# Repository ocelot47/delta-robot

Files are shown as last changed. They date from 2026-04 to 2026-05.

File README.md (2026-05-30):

# Delta Robot Project (WIP)

A personal engineering project to design and build a 3-DOF Delta Robot, from
CAD and 3D-printed parts to embedded control, Python desktop control, motion
testing, and gripper experiments.

## Current Status

- Project stage: **Work in Progress**
- Mechanical/CAD design is available
- Prototype integration and ESP32 control are in progress
- Python GUI is available for serial control, testing, and visualization
- MG90S gripper servo control is included in the current firmware/app flow
- Final calibration and production-ready behavior are not finished yet

## What Is Included Right Now

- CAD assembly snapshots
- STL files for 3D printing (`filein3d_STL`)
- Assembly file (`assembly.sldasm`)
- ESP32 firmware (`napcode/code/code.ino`)
- Python desktop app (`napcode/code/main.py`)
- Camera candy detection module (`napcode/code/handlers/candy_detector.py`)
- Calibration measurement template (`napcode/code/calibration_measurements.md`)
- Reference images used for documentation

## Project Gallery

### Complete Assembly View
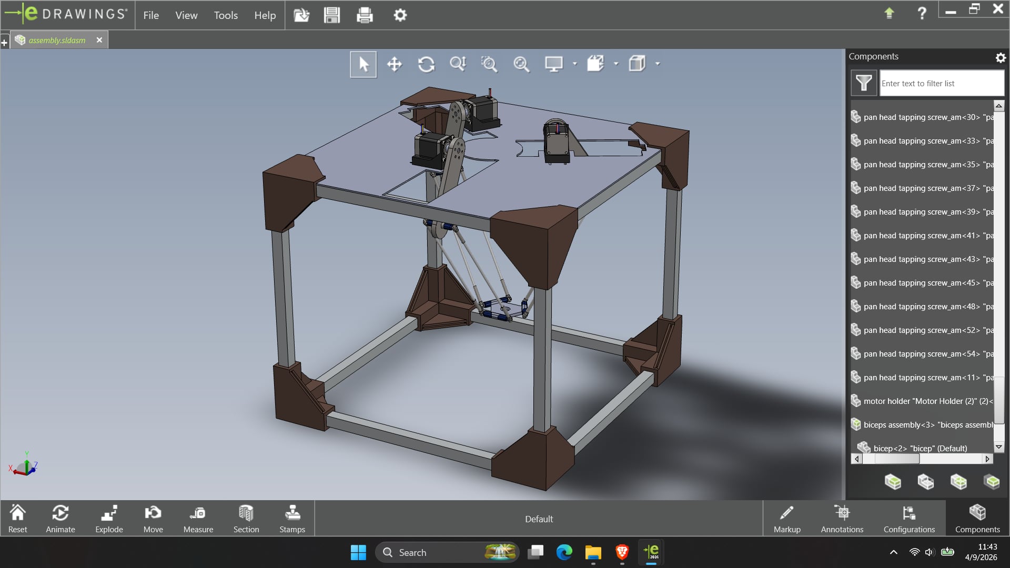
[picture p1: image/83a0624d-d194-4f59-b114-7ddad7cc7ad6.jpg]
Complete assembly CAD view

Overall CAD assembly of the Delta Robot frame, motor mounts, and arm linkage.

### Exploded Assembly View
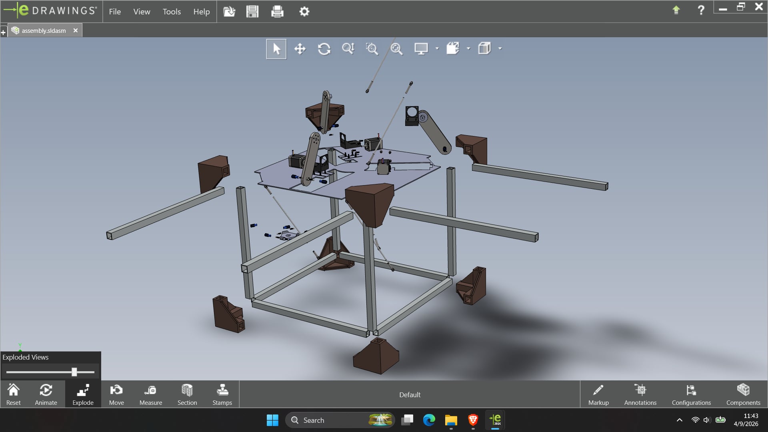
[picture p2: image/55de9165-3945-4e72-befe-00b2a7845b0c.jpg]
Exploded assembly CAD view

Exploded view showing how structural and moving components fit together.

### Top View Measurement
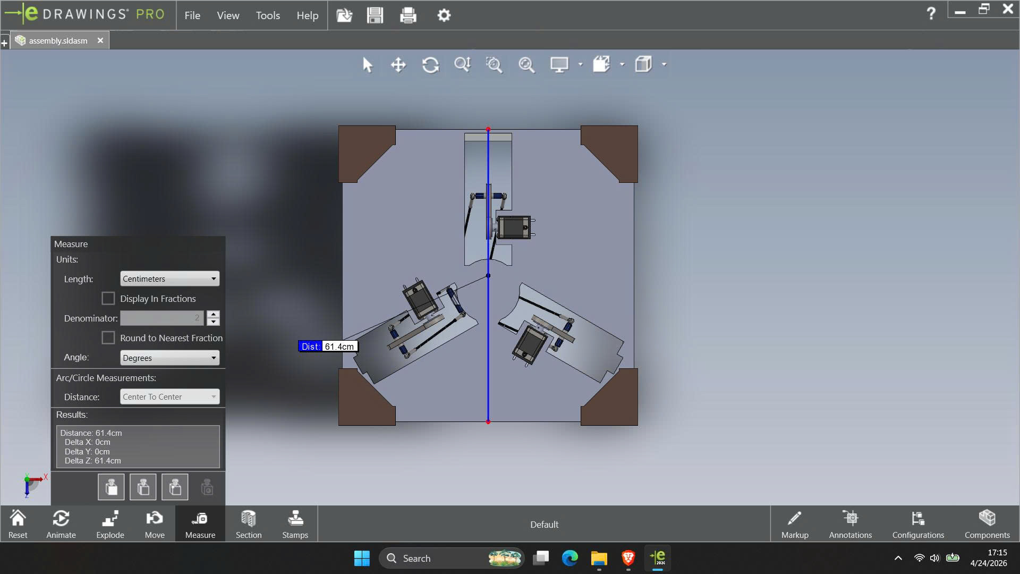
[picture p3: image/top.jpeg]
Top view CAD measurement

Top view with geometric spacing measurement used for frame and actuator placement checks.

### Side View Measurement
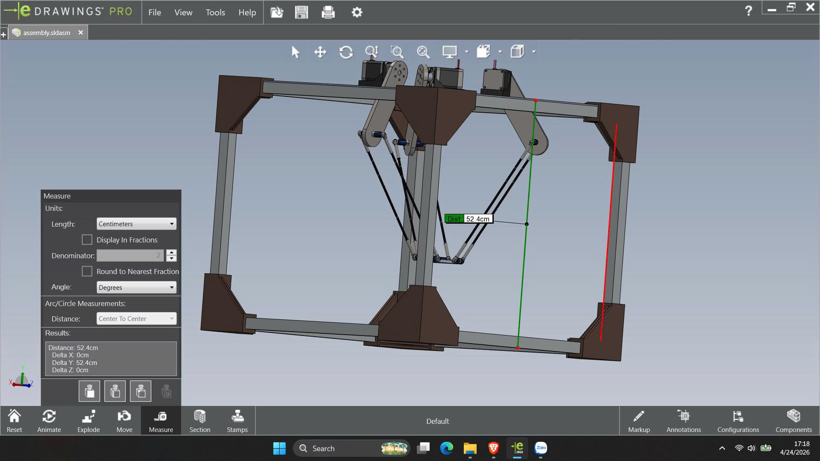
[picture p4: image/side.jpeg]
Side view CAD measurement

Side view with height/clearance measurement for workspace and vertical layout validation.

## Repository Highlights

- `image/`: screenshots, measurement views, and CAD references
- `image/filein3d_STL/`: printable STL component set
- `napcode/code/`: Python desktop app and ESP32 firmware
- `napcode/code/code.ino`: ESP32 JSON-over-Serial firmware
- `napcode/code/main.py`: desktop app entry point
- `napcode/code/handlers/candy_detector.py`: YOLO candy detection helper
- `napcode/code/calibration_measurements.md`: robot measurement worksheet

## Desktop App And Firmware

The desktop app is built with Python, CustomTkinter, PySerial, Matplotlib, and
NumPy, OpenCV, Pillow, and Ultralytics. It provides compact controls on the
left, a Matplotlib robot visualization on the right, menu items for plots,
camera support, candy detection, and a log console at the bottom.

The serial protocol is JSON-over-Serial for the current ESP32 firmware.

## Hardware Mapping

| Signal | GPIO |
|---|---:|
| STEP1 / Motor A | 32 |
| DIR1 / Motor A | 33 |
| STEP2 / Motor B | 18 |
| DIR2 / Motor B | 19 |
| STEP3 / Motor C | 25 |
| DIR3 / Motor C | 26 |
| LIMIT_A | 13 |
| LIMIT_B | 14 |
| LIMIT_C | 23 |
| ENABLE_PIN | 27 |
| MG90S gripper servo signal | 17 |

DRV8825 enable is active low: `LOW = enabled`, `HIGH = disabled`.

Limit switches are NC with `INPUT_PULLUP`: `false = normal`, `true = triggered
or wire fault`.

MG90S gripper:

- Servo signal default: `GPIO17`
- Servo power should use a stable external 5V supply; connect servo GND and
  ESP32 GND together.
- Default open angle: `180 deg`
- Default close angle: `50 deg`
- Default boot/start angle: `70 deg`
- Change these in the UI or in `code.ino` if your gripper geometry needs a
  smaller close limit.

## Install

```bash
pip install customtkinter pyserial matplotlib numpy opencv-python pillow ultralytics
```

Arduino libraries:

- `FastAccelStepper`
- `ArduinoJson` v6.x
- `Delta-Kinematics-Library`
- `ESP32Servo`

## Run

1. Upload `napcode/code/code.ino` to the ESP32.
2. Start the desktop app:

```bash
cd napcode/code
python main.py
```

3. Select the COM port, keep baudrate `115200`, then press `Connect`.

## Test Flow

1. Press `Enable motors`.
2. Check status and limit switches. All limits should be `false` when not pressed.
3. Use `Home A`, `Home B`, `Home C`, or `Home`.
4. Use `JOG / Single Motor` to move one motor.
5. Use `Multi Motor Control` to send `move_abc`.
6. Use `Rotate In Place Test` for the temporary motor-step pattern.
7. Use `Gripper Servo MG90S` to test open/close before running pick/place.
8. Use `Pick From A To B Simulation` for a step-position demo sequence. The
   sequence closes the gripper at Position A and opens it at Position B.
9. Use `Position` + `Move` only after IK config is correct for the real robot.

Candy detection:

- Put `best.pt` in the app folder, next to `main.py`.
- Start the app, scan/select camera, then press `Start Camera`.
- Tick `Detect candy` in the Camera panel.
- The preview draws bounding boxes and red center points. The panel shows the
  first candy center as image pixel coordinates `x/y`.
- Current detection is camera-only. It does not automatically move the robot
  until camera-to-robot calibration is added.

`Emergency Stop` stops app sequences and sends `{"cmd":"stop"}`. It does not
disable the drivers.

Home All behavior:

- Each motor moves toward its NC limit switch until triggered.
- Each motor retracts `HOMING_RETRACT_STEPS` from the just-triggered switch
  position. Default is `200` steps away from the switch.
- Firmware then reports `{"status":"homed","motor":"all"}`.
- The desktop app can optionally run a flexible `Post-Home Drop` move after
  `Home All`. Adjust A/B/C steps, speed, and accel in the app UI; no firmware
  upload is needed for later tuning.
- `Post-Home Drop` is disabled by default because firmware already retracts
  200 steps during homing.
- If the robot moves upward instead of downward, change the signs of A/B/C
  steps in the `Post-Home Drop` section.

## Supported Commands

```json
{"cmd":"enable"}
{"cmd":"disable"}
{"cmd":"stop"}
{"cmd":"status"}
{"cmd":"home"}
{"cmd":"home_motor","motor":"A"}
{"cmd":"move_motor","motor":"A","steps":1000,"speed":2000,"accel":1000}
{"cmd":"jog","motor":"A","dir":1,"steps":100}
{"cmd":"move_abc","a":1000,"b":0,"c":1000,"speed":2000,"accel":1000}
{"cmd":"set_ik_config","arm":100,"rod":250,"base":150,"platform":60,"stepsPerDeg":8.889,"offsetA":0,"offsetB":0,"offsetC":0,"signA":1,"signB":1,"signC":1}
{"cmd":"move_xyz","x":0,"y":0,"z":-200,"speed":2000,"accel":1000}
{"cmd":"gripper_open"}
{"cmd":"gripper_close"}
{"cmd":"gripper_close","angle":50}
{"cmd":"set_gripper","angle":90}
{"cmd":"set_gripper_limits","openAngle":180,"closedAngle":50}
```

Gripper status fields are included in normal status responses:

```json
{"gripperAttached":true,"gripperAngle":180,"gripperOpenAngle":180,"gripperClosedAngle":50}
```

The Program menu from the reference app is present as a placeholder only. The
original repo uses a different command protocol, so program upload was not
copied into this ESP32 JSON app.

## Next Milestones

- Finish mechanical assembly validation
- Refine control firmware and motion sequencing
- Add kinematics and trajectory testing
- Complete calibration measurements
- Tune repeatability and accuracy
- Publish final demo and full build guide

## Tools and Stack

- CAD / 3D design workflow
- 3D-printed mechanical parts (STL)
- Embedded control (Arduino/ESP-style `.ino` workflow)
- ESP32, DRV8825, limit switches, MG90S servo
- Python desktop GUI with serial communication and robot visualization
- OpenCV and Ultralytics YOLO for camera-based candy detection

## Note

This repository is actively updated while the robot is being developed.

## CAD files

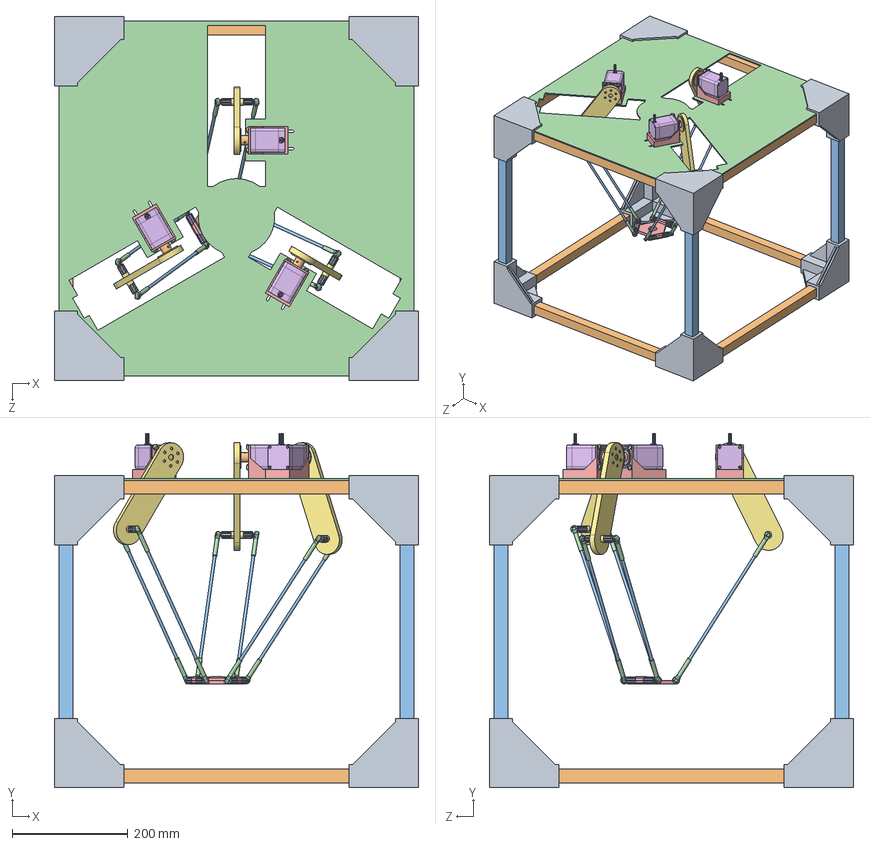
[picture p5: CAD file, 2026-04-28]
image/assembly.sldasm
630.0 x 613.2 x 630.0 mm
frame corner joint x 8
horizontal support frame x 8
vertical stand for frame x 4
motor mounting plate
Motor Holder (2) x 3
NEMA 17 x 3
bicep x 3
ball x 12
ball joint for biceps x 6
rotation transmittor x 3
forearm x 6
socket x 12
Effector platform 1
Ball joint x 6
pan head tapping screw_am x 24

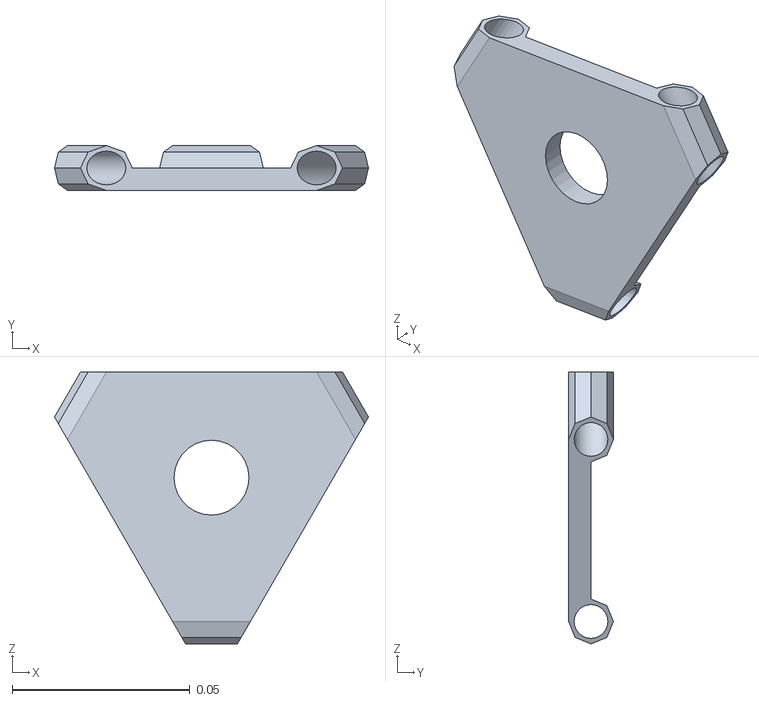
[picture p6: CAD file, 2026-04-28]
image/filein3d_STL/1xeffector_platform1.stl
0.0882 x 0.0126 x 0.0764

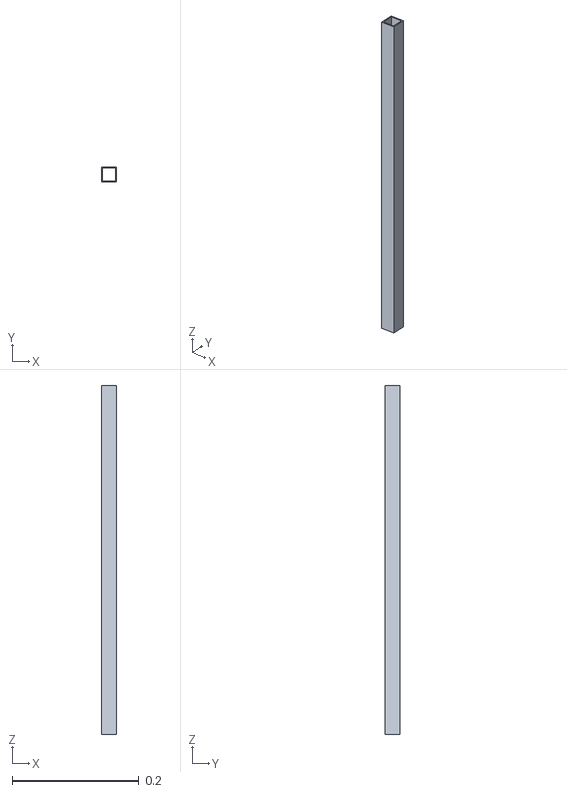
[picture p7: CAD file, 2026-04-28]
image/filein3d_STL/8xhorizontal_support_frame5.stl
0.024 x 0.024 x 0.55

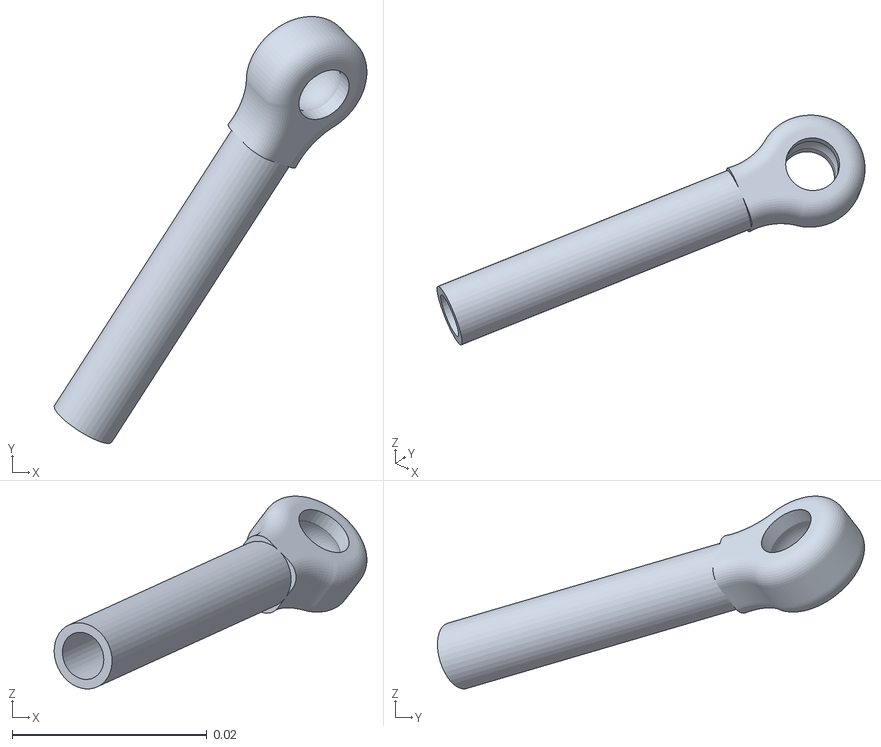
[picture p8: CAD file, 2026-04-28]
image/filein3d_STL/12xsocket_10.stl
0.0321 x 0.0439 x 0.0198

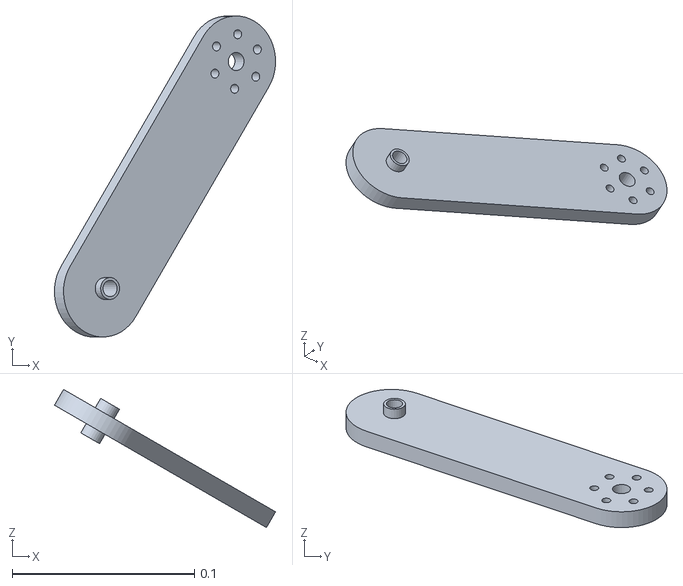
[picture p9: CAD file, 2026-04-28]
image/filein3d_STL/3xbicep_11.stl
0.121 x 0.176 x 0.0759

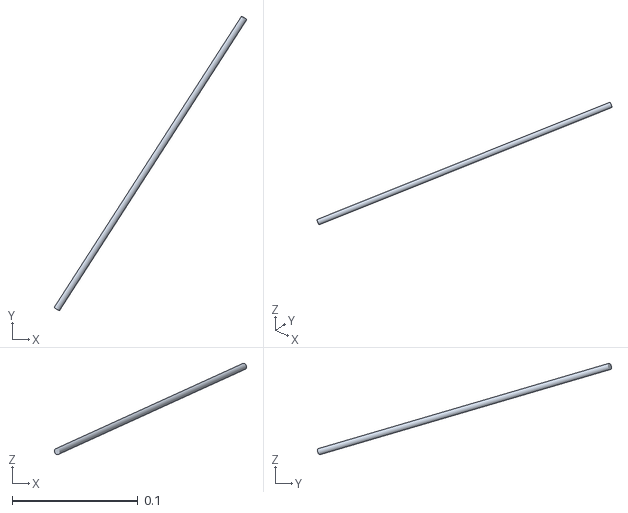
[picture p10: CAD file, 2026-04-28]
image/filein3d_STL/6xforearm_3.stl
0.153 x 0.234 x 0.0725

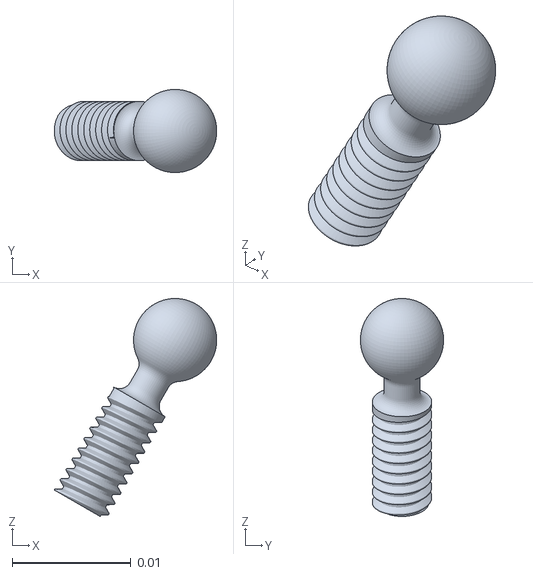
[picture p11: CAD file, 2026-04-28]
image/filein3d_STL/12xball_13.stl
0.0137 x 0.00699 x 0.0183

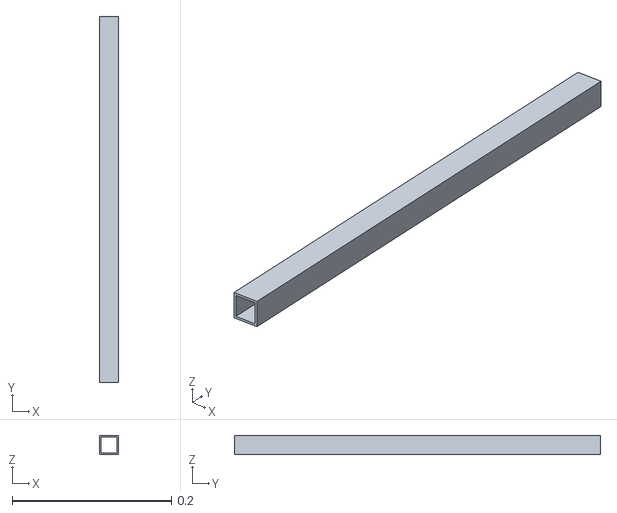
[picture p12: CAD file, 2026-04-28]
image/filein3d_STL/4xvertical_stand_for_frame_6.stl
0.024 x 0.46 x 0.024

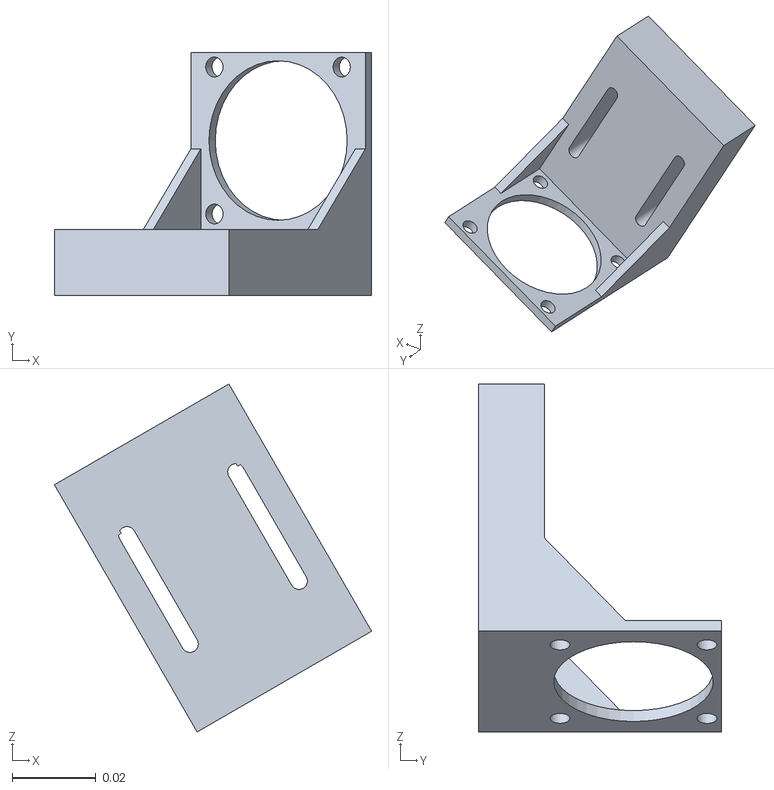
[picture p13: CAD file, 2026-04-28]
image/filein3d_STL/3xmotor_holder_12.stl
0.0756 x 0.058 x 0.0829

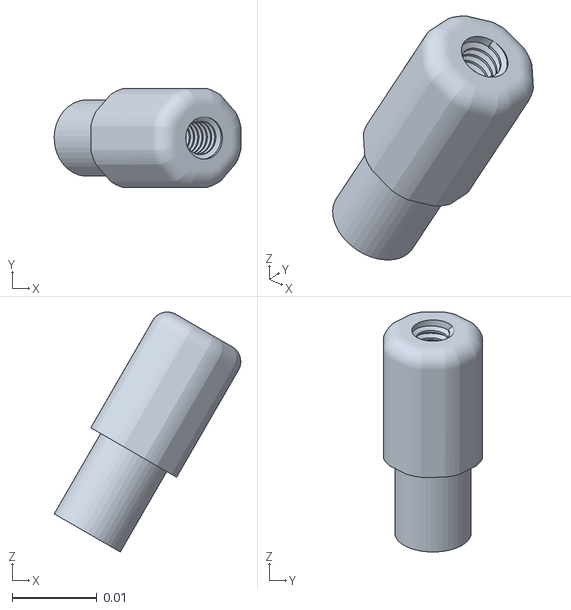
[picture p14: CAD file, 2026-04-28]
image/filein3d_STL/6xball_joint_for_biceps_14.stl
0.022 x 0.0117 x 0.0282

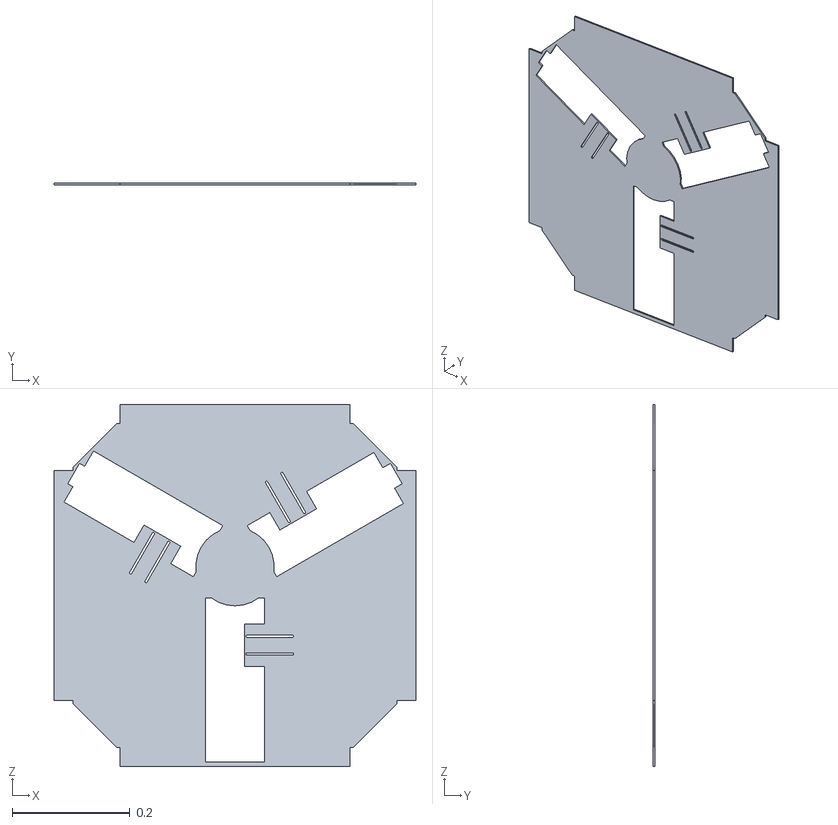
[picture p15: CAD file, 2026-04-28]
image/filein3d_STL/1xmotor_mounting_plate_7.stl
0.614 x 0.003 x 0.614

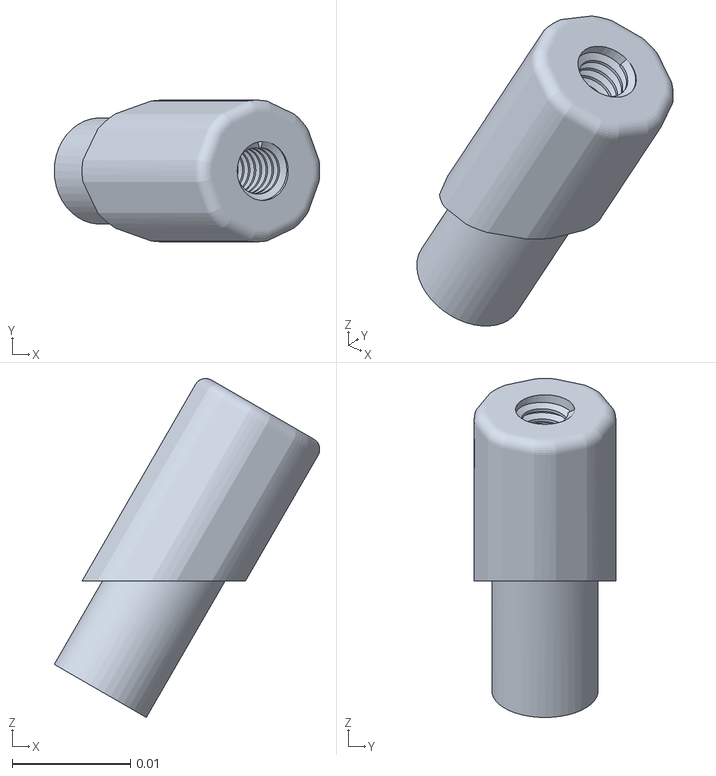
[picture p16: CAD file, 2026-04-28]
image/filein3d_STL/6xball_joint_2.stl
0.0225 x 0.012 x 0.0287

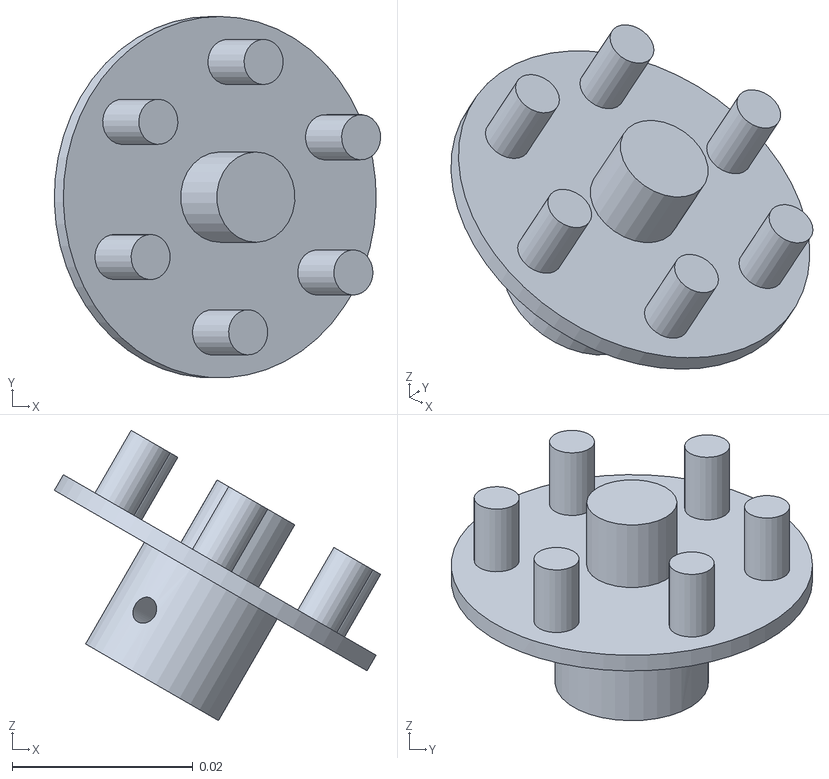
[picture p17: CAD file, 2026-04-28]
image/filein3d_STL/3xrotation_transmittor_9.stl
0.0361 x 0.04 x 0.0321

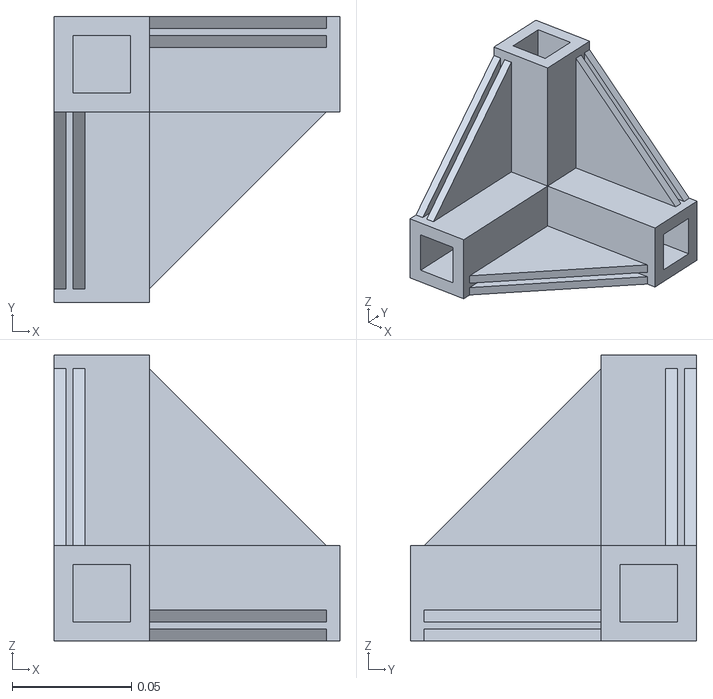
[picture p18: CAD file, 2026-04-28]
image/filein3d_STL/8xframe_corner_joint_4.stl
0.12 x 0.12 x 0.12

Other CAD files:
image/filein3d_STL/12xpan_head_tapping_screw_am-39PHT_4x13x11_6-slot-D-S.stl
image/filein3d_STL/12xpan_head_tapping_screw_am-28PHT_5x13x12_2-slot-D-S.stl

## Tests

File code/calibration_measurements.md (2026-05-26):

# Delta Robot Calibration Measurements

File nay dung de do va ghi thong so robot delta. Sau khi dien xong, gui lai
file nay de tinh:

- `stepsPerDeg`
- `offsetA/B/C`
- `signA/B/C`
- goc home thuc te
- gioi han goc tung motor
- thong so IK `arm/rod/base/platform`
- workspace X/Y/Z cua dau gap
- thong so hien thi 3D trong app

## 1. Thong Tin Chung

Ngay do:

Nguoi do:

Ghi chu robot:

```text

```

Microstep DRV8825 dang dung:

- [ ] Full step
- [ ] 1/2
- [ ] 1/4
- [ ] 1/8
- [ ] 1/16
- [ ] 1/32

Motor step angle:

- [ ] 1.8 deg/step
- [ ] 0.9 deg/step
- [ ] Khac:

Ti so truyen neu co:

```text
Motor truc tiep / pulley / gear:
Gear ratio:
Ghi chu:
```

## 2. Huong Dan Do Goc

Can chon mot moc do goc co dinh va dung nhat quan cho ca 3 motor.

Khuyen nghi:

- Dung mat phang ngang cua tam base lam moc `0 deg`.
- Do goc cua canh tay tren tu truc motor den khop noi voi 2 thanh song song.
- Ghi ro quy uoc:
  - goc duong la tay co len hay ha xuong
  - +step tren app lam tay di len hay di xuong

Moc do goc ban dang dung:

```text

```

Quy uoc goc duong:

```text

```

## 3. Hinh Hoc Robot Delta

Do bang mm. Neu kho do, chup anh va ghi mo ta.

### 3.1 Base Triangle

Tam giac co dinh phia tren, noi 3 truc motor.

| Thong so | Gia tri mm | Cach do / ghi chu |
|---|---:|---|
| Base side: khoang cach truc motor A-B |  |  |
| Base side: khoang cach truc motor B-C |  |  |
| Base side: khoang cach truc motor C-A |  |  |
| Base side trung binh se dung tinh IK |  |  |

Neu truc motor khong nam dung tren dinh tam giac, ghi offset:

```text

```

### 3.2 Platform Triangle

Tam giac nho o dau gap, noi 3 cap thanh song song.

| Thong so | Gia tri mm | Cach do / ghi chu |
|---|---:|---|
| Platform side: khop A-B |  |  |
| Platform side: khop B-C |  |  |
| Platform side: khop C-A |  |  |
| Platform side trung binh se dung tinh IK |  |  |

Offset tu tam platform den dau kep gap:

```text
X offset:
Y offset:
Z offset:
```

### 3.3 Upper Arm

Canh tay tren: tu truc motor den khop noi voi 2 thanh song song.

| Motor | Chieu dai upper arm mm | Ghi chu |
|---|---:|---|
| A |  |  |
| B |  |  |
| C |  |  |
| Trung binh dung tinh IK |  |  |

### 3.4 Forearm Rods

Moi canh co 2 thanh song song tu upper arm xuong platform.

| Canh | Rod 1 mm | Rod 2 mm | Trung binh | Ghi chu |
|---|---:|---:|---:|---|
| A |  |  |  |  |
| B |  |  |  |  |
| C |  |  |  |  |
| Trung binh dung tinh IK |  |  |  |  |

Khoang cach giua 2 rod song song cua moi canh:

| Canh | Khoang cach giua 2 rod mm | Ghi chu |
|---|---:|---|
| A |  |  |
| B |  |  |
| C |  |  |

## 4. Kiem Tra Limit Switch

Truoc khi do goc, kiem tra limit NC:

1. Chay app.
2. Connect ESP32.
3. Khi chua cham, limit phai la `false`.
4. Bam tay tung cong tac, limit tuong ung phai la `true`.

| Limit | Chua cham | Bam tay | Ghi chu |
|---|---|---|---|
| A | false / true | false / true |  |
| B | false / true | false / true |  |
| C | false / true | false / true |  |

## 5. Home All Va Goc Home

Sau khi bam `Home`:

- Motor nao cham limit truoc thi motor do lui `HOMING_RETRACT_STEPS`.
- Motor con lai tiep tuc home.
- Sau khi tat ca homed, app status `homed=true`.

Thu tu cham limit:

```text
1:
2:
3:
```

`HOMING_RETRACT_STEPS` dang dung trong firmware:

```text
200
```

Goc sau Home All:

| Motor | Step status sau Home All | Goc upper arm sau Home All | +step lam tay len/xuong | Ghi chu |
|---|---:|---:|---|---|
| A | 0 |  |  |  |
| B | 0 |  |  |  |
| C | 0 |  |  |  |

## 6. Tim Steps Per Degree

Lam tung motor rieng le. Khuyen nghi speed/accel thap.

Trong app:

```text
JOG / Single Motor
steps = 200
speed = 500
accel = 500
```

Sau moi lan chay, do lai goc upper arm.

### Motor A

| Lan do | Lenh | Step status tren app | Goc do duoc | Ghi chu |
|---|---:|---:|---:|---|
| Home | 0 | 0 |  |  |
| A +200 | +200 |  |  |  |
| A +400 | +400 |  |  |  |
| A -200 | -200 |  |  |  |

### Motor B

| Lan do | Lenh | Step status tren app | Goc do duoc | Ghi chu |
|---|---:|---:|---:|---|
| Home | 0 | 0 |  |  |
| B +200 | +200 |  |  |  |
| B +400 | +400 |  |  |  |
| B -200 | -200 |  |  |  |

### Motor C

| Lan do | Lenh | Step status tren app | Goc do duoc | Ghi chu |
|---|---:|---:|---:|---|
| Home | 0 | 0 |  |  |
| C +200 | +200 |  |  |  |
| C +400 | +400 |  |  |  |
| C -200 | -200 |  |  |  |

## 7. Gioi Han Goc Tung Canh

Muc tieu: tim goc cao nhat co the co len va goc thap nhat co the ha xuong
ma khong cham khung, khong cang rod, khong gay ket co khi.

Di chuyen rat cham:

```text
steps = 50 hoac 100
speed = 300 den 500
accel = 300 den 500
```

### Motor A

| Gioi han | Step status | Goc upper arm | Mo ta co khi |
|---|---:|---:|---|
| Cao nhat / co len toi da |  |  |  |
| Thap nhat / ha xuong toi da |  |  |  |

### Motor B

| Gioi han | Step status | Goc upper arm | Mo ta co khi |
|---|---:|---:|---|
| Cao nhat / co len toi da |  |  |  |
| Thap nhat / ha xuong toi da |  |  |  |

### Motor C

| Gioi han | Step status | Goc upper arm | Mo ta co khi |
|---|---:|---:|---|
| Cao nhat / co len toi da |  |  |  |
| Thap nhat / ha xuong toi da |  |  |  |

## 8. Workspace Dau Gap

Phan nay do gioi han thuc te cua diem dau gap/kep.

Chon truc toa do:

```text
X duong huong ve:
Y duong huong ve:
Z duong huong ve:
Goc toa do dat tai:
```

### 8.1 Tam Workspace

Vi tri dau gap sau Home All:

```text
X =
Y =
Z =
```

### 8.2 Gioi Han Len/Xuong

Tai tam XY, di chuyen Z len/xuong cham nhat co the.

| Gioi han | X | Y | Z | Step A | Step B | Step C | Ghi chu |
|---|---:|---:|---:|---:|---:|---:|---|
| Z cao nhat |  |  |  |  |  |  |  |
| Z thap nhat |  |  |  |  |  |  |  |

### 8.3 Gioi Han Trai/Phai/Truoc/Sau

O mot do cao Z an toan, tim gioi han X/Y.

Do cao Z khi test:

```text
Z =
```

| Huong | X | Y | Z | Step A | Step B | Step C | Ghi chu |
|---|---:|---:|---:|---:|---:|---:|---|
| Tien truoc toi da |  |  |  |  |  |  |  |
| Lui sau toi da |  |  |  |  |  |  |  |
| Trai toi da |  |  |  |  |  |  |  |
| Phai toi da |  |  |  |  |  |  |  |

### 8.4 Diem Test IK Neu Co

Neu app/firmware da move_xyz duoc, ghi diem command va diem thuc te.

| Diem | X lenh | Y lenh | Z lenh | X thuc | Y thuc | Z thuc | Ghi chu |
|---|---:|---:|---:|---:|---:|---:|---|
| P1 | 0 | 0 |  |  |  |  |  |
| P2 |  |  |  |  |  |  |  |
| P3 |  |  |  |  |  |  |  |
| P4 |  |  |  |  |  |  |  |

## 9. Gripper Servo MG90S

Goc start firmware hien tai:

```text
70 deg
```

| Trang thai | Goc command | Trang thai thuc te | Ghi chu |
|---|---:|---|---|
| Start | 70 |  |  |
| Open | 180 |  |  |
| Close | 50 |  |  |
| Close nho nhat an toan |  |  |  |

## 10. Loi / Bat Thuong Khi Do

```text

```

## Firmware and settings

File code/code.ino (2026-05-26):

// Delta Robot - ESP32 motor test + inverse kinematics firmware
//
// Protocol: JSON over Serial at 115200 baud.
// Limit switches are NC: normal = LOW, triggered/wire fault = HIGH.

#include <ArduinoJson.h>
#include <DeltaKinematics.h>
#include <FastAccelStepper.h>
#include <ESP32Servo.h>

// Stepper pins
#define STEP1  32
#define DIR1   33
#define STEP2  18
#define DIR2   19
#define STEP3  25
#define DIR3   26

// NC limit switches: normal = LOW, triggered or wire fault = HIGH.
#define LIMIT_A 13
#define LIMIT_B 14
#define LIMIT_C 23

// DRV8825 common enable: LOW = enabled, HIGH = disabled.
#define ENABLE_PIN 27

// MG90S gripper servo. Change this pin if GPIO17 is already used on your PCB.
#define GRIPPER_SERVO_PIN 17

const uint32_t DEFAULT_SPEED = 2000;
const uint32_t DEFAULT_ACCEL = 1000;

const int GRIPPER_SERVO_MIN_US = 500;
const int GRIPPER_SERVO_MAX_US = 2500;
const int GRIPPER_HARD_MIN_ANGLE = 0;
const int GRIPPER_HARD_MAX_ANGLE = 180;
const int GRIPPER_DEFAULT_START_ANGLE = 70;
const int GRIPPER_DEFAULT_OPEN_ANGLE = 180;
const int GRIPPER_DEFAULT_CLOSED_ANGLE = 50;

// Homing moves "bung ra" in HOME_OUT_SIGN direction until the switch triggers,
// then retracts ("thu lai") in the opposite direction until the switch releases.
const uint32_t HOMING_SPEED = 800;
const uint32_t HOMING_ACCEL = 800;
const int32_t HOME_OUT_SIGN_A = 1;
const int32_t HOME_OUT_SIGN_B = 1;
const int32_t HOME_OUT_SIGN_C = 1;
const int32_t HOMING_SEARCH_CHUNK_STEPS = 300;
const int32_t HOMING_RETRACT_STEPS = 200;
const int32_t HOMING_MAX_RETRACT_STEPS = 6000;
// IK defaults. Tune these for the real robot.
float ikArm = 100.0f;
float ikRod = 250.0f;
float ikBase = 150.0f;
float ikPlatform = 60.0f;
float stepsPerDeg = 8.889f;
int32_t ikOffsetA = 0;
int32_t ikOffsetB = 0;
int32_t ikOffsetC = 0;
int32_t ikSignA = 1;
int32_t ikSignB = 1;
int32_t ikSignC = 1;

FastAccelStepperEngine engine = FastAccelStepperEngine();
FastAccelStepper *motorA = nullptr;
FastAccelStepper *motorB = nullptr;
FastAccelStepper *motorC = nullptr;
Servo gripperServo;

DeltaKinematics DK(100.0f, 250.0f, 150.0f, 60.0f);
StaticJsonDocument<384> doc;

bool driversEnabled = false;
bool homedA = false;
bool homedB = false;
bool homedC = false;
bool movementPending = false;
bool homingActive = false;
bool homingAll = false;
uint8_t homingSearchMask = 0;
uint8_t homingRetractMask = 0;
int32_t homingRetractedA = 0;
int32_t homingRetractedB = 0;
int32_t homingRetractedC = 0;
bool homingRetractStartedA = false;
bool homingRetractStartedB = false;
bool homingRetractStartedC = false;
int32_t activeDirA = 0;
int32_t activeDirB = 0;
int32_t activeDirC = 0;

bool pendingIkMove = false;
bool xyzValid = false;
float lastX = 0.0f;
float lastY = 0.0f;
float lastZ = 0.0f;
float lastThetaA = 0.0f;
float lastThetaB = 0.0f;
float lastThetaC = 0.0f;
float pendingX = 0.0f;
float pendingY = 0.0f;
float pendingZ = 0.0f;
float pendingThetaA = 0.0f;
float pendingThetaB = 0.0f;
float pendingThetaC = 0.0f;

bool gripperAttached = false;
int gripperServoChannel = -1;
int gripperAngle = GRIPPER_DEFAULT_START_ANGLE;
int gripperOpenAngle = GRIPPER_DEFAULT_OPEN_ANGLE;
int gripperClosedAngle = GRIPPER_DEFAULT_CLOSED_ANGLE;

enum MotorBit {
  MOTOR_A_BIT = 1,
  MOTOR_B_BIT = 2,
  MOTOR_C_BIT = 4,
};

bool limitA() { return digitalRead(LIMIT_A) == HIGH; }
bool limitB() { return digitalRead(LIMIT_B) == HIGH; }
bool limitC() { return digitalRead(LIMIT_C) == HIGH; }

int32_t signOf(int32_t value) {
  // Trả về dấu của số step để biết motor đang đi theo chiều nào.
  if (value > 0) return 1;
  if (value < 0) return -1;
  return 0;
}

int32_t abs32(int32_t value) {
  // Lấy trị tuyệt đối cho số int32_t.
  return value < 0 ? -value : value;
}

int32_t homeOutSign(uint8_t bit) {
  // Trả về chiều đi ra ngoài để tìm công tắc hành trình của từng motor.
  if (bit == MOTOR_A_BIT) return HOME_OUT_SIGN_A;
  if (bit == MOTOR_B_BIT) return HOME_OUT_SIGN_B;
  if (bit == MOTOR_C_BIT) return HOME_OUT_SIGN_C;
  return -1;
}

int32_t pos(FastAccelStepper *stepper) {
  // Đọc vị trí step hiện tại của motor, nếu motor chưa init thì trả 0.
  return stepper ? stepper->getCurrentPosition() : 0;
}

bool isBusy() {
  // Kiểm tra có motor nào đang chạy không.
  return (motorA && motorA->isRunning()) ||
         (motorB && motorB->isRunning()) ||
         (motorC && motorC->isRunning());
}

void sendJson(JsonDocument &out) {
  // Gửi một object JSON ra Serial, kết thúc bằng newline.
  serializeJson(out, Serial);
  Serial.println();
}

void addCommonStatus(JsonDocument &out) {
  // Gắn các field status chung vào mọi response gửi về app.
  out["a"] = pos(motorA);
  out["b"] = pos(motorB);
  out["c"] = pos(motorC);
  out["limitA"] = limitA();
  out["limitB"] = limitB();
  out["limitC"] = limitC();
  out["enabled"] = driversEnabled;
  out["homed"] = homedA && homedB && homedC;
  out["moving"] = isBusy() || homingActive;
  out["gripperAttached"] = gripperAttached;
  out["gripperAngle"] = gripperAngle;
  out["gripperOpenAngle"] = gripperOpenAngle;
  out["gripperClosedAngle"] = gripperClosedAngle;
  out["xyzValid"] = xyzValid;
  if (xyzValid) {
    out["x"] = lastX;
    out["y"] = lastY;
    out["z"] = lastZ;
    out["thetaA"] = lastThetaA;
    out["thetaB"] = lastThetaB;
    out["thetaC"] = lastThetaC;
  }
}

void sendStatus(const char *status = nullptr, const char *motor = nullptr) {
  // Gửi status chuẩn về app, có thể kèm tên motor đang xử lý.
  StaticJsonDocument<512> out;
  out["status"] = status ? status : ((isBusy() || homingActive) ? "moving" : "idle");
  if (motor) out["motor"] = motor;
  addCommonStatus(out);
  sendJson(out);
}

void sendError(const char *msg) {
  // Gửi lỗi về app nhưng vẫn kèm status hiện tại để UI cập nhật được.
  StaticJsonDocument<512> out;
  out["status"] = "error";
  out["msg"] = msg;
  addCommonStatus(out);
  sendJson(out);
}

void setDrivers(bool enabled) {
  // Điều khiển ENABLE chung của 3 DRV8825: LOW bật, HIGH tắt.
  driversEnabled = enabled;
  digitalWrite(ENABLE_PIN, enabled ? LOW : HIGH);
}

int constrainGripperAngle(int angle) {
  // Giới hạn góc servo kẹp trong khoảng open/close đã cấu hình.
  int lo = min(gripperOpenAngle, gripperClosedAngle);
  int hi = max(gripperOpenAngle, gripperClosedAngle);
  return constrain(angle, lo, hi);
}

void writeGripperAngle(int angle) {
  // Ghi góc servo kẹp và lưu lại gripperAngle để trả status.
  gripperAngle = constrainGripperAngle(angle);
  if (gripperAttached) {
    gripperServo.write(gripperAngle);
  }
}

void setGripperLimits(int openAngle, int closedAngle) {
  // Cập nhật giới hạn mở/kẹp của servo từ app.
  gripperOpenAngle = constrain(openAngle, GRIPPER_HARD_MIN_ANGLE, GRIPPER_HARD_MAX_ANGLE);
  gripperClosedAngle = constrain(closedAngle, GRIPPER_HARD_MIN_ANGLE, GRIPPER_HARD_MAX_ANGLE);
  writeGripperAngle(gripperAngle);
}

void applyConfig(uint32_t speed, uint32_t accel) {
  // Áp tốc độ/gia tốc cho cả 3 stepper.
  speed = max((uint32_t)1, speed);
  accel = max((uint32_t)1, accel);
  if (motorA) { motorA->setSpeedInHz(speed); motorA->setAcceleration(accel); }
  if (motorB) { motorB->setSpeedInHz(speed); motorB->setAcceleration(accel); }
  if (motorC) { motorC->setSpeedInHz(speed); motorC->setAcceleration(accel); }
}

void clearActiveDirs() {
  // Xóa chiều chạy hiện tại, dùng sau khi dừng hoặc move xong.
  activeDirA = 0;
  activeDirB = 0;
  activeDirC = 0;
}

void cancelPendingIk() {
  // Hủy move_xyz đang chờ commit nếu move bị stop/lỗi.
  pendingIkMove = false;
}

void stopAllMotors() {
  // Dừng khẩn cấp toàn bộ motor và reset các state homing/move.
  if (motorA) motorA->forceStop();
  if (motorB) motorB->forceStop();
  if (motorC) motorC->forceStop();
  movementPending = false;
  homingActive = false;
  homingSearchMask = 0;
  homingRetractMask = 0;
  homingAll = false;
  homingRetractStartedA = false;
  homingRetractStartedB = false;
  homingRetractStartedC = false;
  clearActiveDirs();
  cancelPendingIk();
}

uint8_t bitForMotor(const char *motor) {
  // Chuyển tên motor A/B/C hoặc 1/2/3 thành bit mask nội bộ.
  if (!motor) return 0;
  if (strcmp(motor, "A") == 0 || strcmp(motor, "1") == 0) return MOTOR_A_BIT;
  if (strcmp(motor, "B") == 0 || strcmp(motor, "2") == 0) return MOTOR_B_BIT;
  if (strcmp(motor, "C") == 0 || strcmp(motor, "3") == 0) return MOTOR_C_BIT;
  return 0;
}

const char *nameForBit(uint8_t bit) {
  // Chuyển bit mask motor thành tên A/B/C để trả status.
  if (bit == MOTOR_A_BIT) return "A";
  if (bit == MOTOR_B_BIT) return "B";
  if (bit == MOTOR_C_BIT) return "C";
  return "?";
}

bool limitForBit(uint8_t bit) {
  // Đọc limit switch tương ứng với motor bit.
  if (bit == MOTOR_A_BIT) return limitA();
  if (bit == MOTOR_B_BIT) return limitB();
  if (bit == MOTOR_C_BIT) return limitC();
  return true;
}

FastAccelStepper *stepperForBit(uint8_t bit) {
  // Lấy pointer stepper tương ứng với motor bit.
  if (bit == MOTOR_A_BIT) return motorA;
  if (bit == MOTOR_B_BIT) return motorB;
  if (bit == MOTOR_C_BIT) return motorC;
  return nullptr;
}

void markHomed(uint8_t bit) {
  // Đánh dấu motor đã homed.
  if (bit == MOTOR_A_BIT) homedA = true;
  if (bit == MOTOR_B_BIT) homedB = true;
  if (bit == MOTOR_C_BIT) homedC = true;
}

void clearHomed(uint8_t bit) {
  // Xóa trạng thái homed của motor khi bắt đầu homing lại hoặc lỗi.
  if (bit == MOTOR_A_BIT) homedA = false;
  if (bit == MOTOR_B_BIT) homedB = false;
  if (bit == MOTOR_C_BIT) homedC = false;
}

int32_t &homingRetractedForBit(uint8_t bit) {
  // Tham chiếu tới biến đếm step đã lùi sau khi chạm limit.
  if (bit == MOTOR_A_BIT) return homingRetractedA;
  if (bit == MOTOR_B_BIT) return homingRetractedB;
  return homingRetractedC;
}

bool &homingRetractStartedForBit(uint8_t bit) {
  // Tham chiếu tới cờ motor đã bắt đầu lùi khỏi limit hay chưa.
  if (bit == MOTOR_A_BIT) return homingRetractStartedA;
  if (bit == MOTOR_B_BIT) return homingRetractStartedB;
  return homingRetractStartedC;
}

void moveHomingSearchChunk(uint8_t bit) {
  // Cho một motor đi từng đoạn nhỏ theo chiều tìm limit.
  FastAccelStepper *stepper = stepperForBit(bit);
  if (stepper && !stepper->isRunning()) {
    stepper->move(homeOutSign(bit) * HOMING_SEARCH_CHUNK_STEPS);
  }
}

void moveHomingRetractChunk(uint8_t bit) {
  // Cho motor đã chạm limit lùi đúng HOMING_RETRACT_STEPS rồi dừng.
  FastAccelStepper *stepper = stepperForBit(bit);
  if (!stepper || stepper->isRunning()) return;
  int32_t steps = -homeOutSign(bit) * HOMING_RETRACT_STEPS;
  stepper->move(steps);
  homingRetractedForBit(bit) += abs32(steps);
  homingRetractStartedForBit(bit) = true;
}

bool limitBlocksDelta(uint8_t bit, int32_t delta) {
  // Chặn move nếu limit đang triggered và lệnh còn đi tiếp vào limit.
  if (!limitForBit(bit)) return false;
  int32_t dir = signOf(delta);
  if (dir == 0) return true;
  return dir == homeOutSign(bit);
}

bool movingIntoLimit() {
  // Kiểm tra motor đang chạy có đâm vào limit hay không.
  return (limitA() && activeDirA == HOME_OUT_SIGN_A) ||
         (limitB() && activeDirB == HOME_OUT_SIGN_B) ||
         (limitC() && activeDirC == HOME_OUT_SIGN_C);
}

bool canStartMotion(int32_t a, int32_t b, int32_t c) {
  // Kiểm tra điều kiện trước khi bắt đầu move_abc/move_motor.
  if (!driversEnabled) {
    sendError("motors_disabled");
    return false;
  }
  if (homingActive || isBusy()) {
    sendError("busy");
    return false;
  }
  if (limitBlocksDelta(MOTOR_A_BIT, a) ||
      limitBlocksDelta(MOTOR_B_BIT, b) ||
      limitBlocksDelta(MOTOR_C_BIT, c)) {
    sendError("limit_triggered_reverse_allowed_only");
    return false;
  }
  return true;
}

bool startMoveABC(int32_t a, int32_t b, int32_t c, uint32_t speed,
                  uint32_t accel, bool fromIk = false) {
  // Bắt đầu chạy tương đối 3 motor theo số step A/B/C.
  if (!canStartMotion(a, b, c)) return false;
  applyConfig(speed, accel);

  activeDirA = signOf(a);
  activeDirB = signOf(b);
  activeDirC = signOf(c);

  if (a != 0 && motorA) motorA->move(a);
  if (b != 0 && motorB) motorB->move(b);
  if (c != 0 && motorC) motorC->move(c);

  if (a == 0 && b == 0 && c == 0) {
    clearActiveDirs();
    sendStatus("done");
    return true;
  }

  movementPending = true;
  pendingIkMove = fromIk;
  if (!fromIk) {
    xyzValid = false;
  }
  sendStatus("moving");
  return true;
}

void commitPendingIk() {
  // Khi move_xyz hoàn tất, commit x/y/z/theta cuối cùng vào status.
  if (!pendingIkMove) return;
  lastX = pendingX;
  lastY = pendingY;
  lastZ = pendingZ;
  lastThetaA = pendingThetaA;
  lastThetaB = pendingThetaB;
  lastThetaC = pendingThetaC;
  xyzValid = true;
  pendingIkMove = false;
}

int32_t thetaToSteps(float theta, int32_t signValue, int32_t offset) {
  // Đổi góc IK sang target step theo sign/offset từng motor.
  return offset + (int32_t)(theta * stepsPerDeg * (float)signValue);
}

void startMoveXYZ(float x, float y, float z, uint32_t speed, uint32_t accel) {
  // Tính IK cho XYZ rồi chuyển thành move_abc tương đối.
  if (DK.inverse(x, y, z) != 1) {
    sendError("ik_fail");
    return;
  }

  int32_t targetA = thetaToSteps(DK.a, ikSignA, ikOffsetA);
  int32_t targetB = thetaToSteps(DK.b, ikSignB, ikOffsetB);
  int32_t targetC = thetaToSteps(DK.c, ikSignC, ikOffsetC);
  int32_t deltaA = targetA - pos(motorA);
  int32_t deltaB = targetB - pos(motorB);
  int32_t deltaC = targetC - pos(motorC);

  pendingX = x;
  pendingY = y;
  pendingZ = z;
  pendingThetaA = DK.a;
  pendingThetaB = DK.b;
  pendingThetaC = DK.c;

  if (deltaA == 0 && deltaB == 0 && deltaC == 0) {
    pendingIkMove = true;
    commitPendingIk();
    sendStatus("done");
    return;
  }

  if (!startMoveABC(deltaA, deltaB, deltaC, speed, accel, true)) {
    cancelPendingIk();
  }
}

void startHomeMask(uint8_t mask, bool all) {
  // Khởi động homing cho một motor hoặc cả 3 motor.
  if (!driversEnabled) {
    sendError("motors_disabled");
    return;
  }
  if (homingActive || isBusy()) {
    sendError("busy");
    return;
  }

  homingSearchMask = mask;
  homingRetractMask = 0;
  homingAll = all;
  homingActive = homingSearchMask != 0;
  homingRetractedA = 0;
  homingRetractedB = 0;
  homingRetractedC = 0;
  homingRetractStartedA = false;
  homingRetractStartedB = false;
  homingRetractStartedC = false;
  applyConfig(HOMING_SPEED, HOMING_ACCEL);

  if (homingSearchMask & MOTOR_A_BIT) clearHomed(MOTOR_A_BIT);
  if (homingSearchMask & MOTOR_B_BIT) clearHomed(MOTOR_B_BIT);
  if (homingSearchMask & MOTOR_C_BIT) clearHomed(MOTOR_C_BIT);
  xyzValid = false;
  cancelPendingIk();

  sendStatus("homing", all ? "all" : nameForBit(mask));
}

void processHoming() {
  // State machine homing: motor nào chạm trước thì lùi, motor khác tiếp tục tìm limit.
  if (!homingActive) return;

  uint8_t bits[] = {MOTOR_A_BIT, MOTOR_B_BIT, MOTOR_C_BIT};
  for (uint8_t i = 0; i < 3; i++) {
    uint8_t bit = bits[i];
    FastAccelStepper *stepper = stepperForBit(bit);
    if (!stepper) continue;

    if (homingSearchMask & bit) {
      if (limitForBit(bit)) {
        stepper->forceStop();
        stepper->setCurrentPosition(0);
        homingSearchMask &= ~bit;
        homingRetractMask |= bit;
        homingRetractedForBit(bit) = 0;
        homingRetractStartedForBit(bit) = false;
        sendStatus("homing_retract", nameForBit(bit));
        moveHomingRetractChunk(bit);
      } else {
        moveHomingSearchChunk(bit);
      }
      continue;
    }

    if (homingRetractMask & bit) {
      if (!homingRetractStartedForBit(bit)) {
        moveHomingRetractChunk(bit);
        continue;
      }

      if (stepper->isRunning()) continue;

      if (!limitForBit(bit)) {
        stepper->setCurrentPosition(0);
        markHomed(bit);
        homingRetractMask &= ~bit;
        sendStatus("homed", nameForBit(bit));
      } else {
        clearHomed(bit);
        homingRetractMask &= ~bit;
        sendError("home_retract_200_steps_limit_still_triggered");
        return;
      }
    }
  }

  if (homingSearchMask == 0 && homingRetractMask == 0) {
    homingActive = false;
    if (homingAll) {
      sendStatus("homed", "all");
    }
    homingAll = false;
  }
}

void handleCommand(const String &line) {
  // Parse JSON command từ app và dispatch tới chức năng tương ứng.
  doc.clear();
  DeserializationError err = deserializeJson(doc, line);
  if (err) {
    sendError("json_parse");
    return;
  }

  const char *cmd = doc["cmd"] | "";

  if (strcmp(cmd, "status") == 0) {
    sendStatus();
    return;
  }

  if (strcmp(cmd, "enable") == 0) {
    setDrivers(true);
    sendStatus("ok");
    return;
  }

  if (strcmp(cmd, "disable") == 0) {
    stopAllMotors();
    setDrivers(false);
    sendStatus("ok");
    return;
  }

  if (strcmp(cmd, "stop") == 0) {
    stopAllMotors();
    sendStatus("idle");
    return;
  }

  if (strcmp(cmd, "gripper_open") == 0) {
    writeGripperAngle(gripperOpenAngle);
    sendStatus("ok");
    return;
  }

  if (strcmp(cmd, "gripper_close") == 0) {
    int angle = doc["angle"] | gripperClosedAngle;
    writeGripperAngle(angle);
    sendStatus("ok");
    return;
  }

  if (strcmp(cmd, "set_gripper") == 0) {
    int angle = doc["angle"] | gripperAngle;
    writeGripperAngle(angle);
    sendStatus("ok");
    return;
  }

  if (strcmp(cmd, "set_gripper_limits") == 0) {
    int openAngle = doc["openAngle"] | gripperOpenAngle;
    int closedAngle = doc["closedAngle"] | gripperClosedAngle;
    setGripperLimits(openAngle, closedAngle);
    sendStatus("ok");
    return;
  }

  if (strcmp(cmd, "home") == 0) {
    startHomeMask(MOTOR_A_BIT | MOTOR_B_BIT | MOTOR_C_BIT, true);
    return;
  }

  if (strcmp(cmd, "home_motor") == 0) {
    const char *motor = doc["motor"] | "";
    uint8_t bit = bitForMotor(motor);
    if (bit == 0) {
      sendError("invalid_motor");
      return;
    }
    startHomeMask(bit, false);
    return;
  }

  if (strcmp(cmd, "jog") == 0) {
    const char *motor = doc["motor"] | "";
    uint8_t bit = bitForMotor(motor);
    if (bit == 0) {
      sendError("invalid_motor");
      return;
    }
    int dir = doc["dir"] | 1;
    int32_t steps = doc["steps"] | 100;
    uint32_t speed = doc["speed"] | DEFAULT_SPEED;
    uint32_t accel = doc["accel"] | DEFAULT_ACCEL;
    int32_t signedSteps = abs32(steps) * (dir >= 0 ? 1 : -1);
    int32_t a = 0, b = 0, c = 0;
    if (bit == MOTOR_A_BIT) a = signedSteps;
    if (bit == MOTOR_B_BIT) b = signedSteps;
    if (bit == MOTOR_C_BIT) c = signedSteps;
    startMoveABC(a, b, c, speed, accel);
    return;
  }

  if (strcmp(cmd, "move_motor") == 0) {
    const char *motor = doc["motor"] | "";
    uint8_t bit = bitForMotor(motor);
    if (bit == 0) {
      sendError("invalid_motor");
      return;
    }
    int32_t steps = doc["steps"] | 0;
    uint32_t speed = doc["speed"] | DEFAULT_SPEED;
    uint32_t accel = doc["accel"] | DEFAULT_ACCEL;
    int32_t a = 0, b = 0, c = 0;
    if (bit == MOTOR_A_BIT) a = steps;
    if (bit == MOTOR_B_BIT) b = steps;
    if (bit == MOTOR_C_BIT) c = steps;
    startMoveABC(a, b, c, speed, accel);
    return;
  }

  if (strcmp(cmd, "move_abc") == 0) {
    int32_t a = doc["a"] | 0;
    int32_t b = doc["b"] | 0;
    int32_t c = doc["c"] | 0;
    uint32_t speed = doc["speed"] | DEFAULT_SPEED;
    uint32_t accel = doc["accel"] | DEFAULT_ACCEL;
    startMoveABC(a, b, c, speed, accel);
    return;
  }

  if (strcmp(cmd, "move_xyz") == 0) {
    float x = doc["x"] | 0.0f;
    float y = doc["y"] | 0.0f;
    float z = doc["z"] | -200.0f;
    uint32_t speed = doc["speed"] | DEFAULT_SPEED;
    uint32_t accel = doc["accel"] | DEFAULT_ACCEL;
    startMoveXYZ(x, y, z, speed, accel);
    return;
  }

  if (strcmp(cmd, "set_ik_config") == 0) {
    ikArm = doc["arm"] | ikArm;
    ikRod = doc["rod"] | ikRod;
    ikBase = doc["base"] | ikBase;
    ikPlatform = doc["platform"] | ikPlatform;
    stepsPerDeg = doc["stepsPerDeg"] | stepsPerDeg;
    ikOffsetA = doc["offsetA"] | ikOffsetA;
    ikOffsetB = doc["offsetB"] | ikOffsetB;
    ikOffsetC = doc["offsetC"] | ikOffsetC;
    ikSignA = doc["signA"] | ikSignA;
    ikSignB = doc["signB"] | ikSignB;
    ikSignC = doc["signC"] | ikSignC;
    ikSignA = ikSignA >= 0 ? 1 : -1;
    ikSignB = ikSignB >= 0 ? 1 : -1;
    ikSignC = ikSignC >= 0 ? 1 : -1;
    DK = DeltaKinematics(ikArm, ikRod, ikBase, ikPlatform);
    sendStatus("ok");
    return;
  }

  sendError("unknown_cmd");
}

void setup() {
  // Khởi tạo Serial, GPIO, servo, stepper và gửi boot status.
  Serial.begin(115200);

  pinMode(LIMIT_A, INPUT_PULLUP);
  pinMode(LIMIT_B, INPUT_PULLUP);
  pinMode(LIMIT_C, INPUT_PULLUP);
  pinMode(ENABLE_PIN, OUTPUT);
  setDrivers(false);

  gripperServo.setPeriodHertz(50);
  gripperServoChannel = gripperServo.attach(
    GRIPPER_SERVO_PIN,
    GRIPPER_SERVO_MIN_US,
    GRIPPER_SERVO_MAX_US
  );
  gripperAttached = gripperServoChannel >= 0;
  writeGripperAngle(GRIPPER_DEFAULT_START_ANGLE);

  engine.init();

  motorA = engine.stepperConnectToPin(STEP1);
  motorB = engine.stepperConnectToPin(STEP2);
  motorC = engine.stepperConnectToPin(STEP3);

  if (motorA) { motorA->setDirectionPin(DIR1); motorA->setCurrentPosition(0); }
  if (motorB) { motorB->setDirectionPin(DIR2); motorB->setCurrentPosition(0); }
  if (motorC) { motorC->setDirectionPin(DIR3); motorC->setCurrentPosition(0); }
  applyConfig(DEFAULT_SPEED, DEFAULT_ACCEL);

  StaticJsonDocument<512> out;
  out["boot"] = "delta_motor_test_ik_ready";
  out["status"] = "idle";
  addCommonStatus(out);
  sendJson(out);
}

void loop() {
  // Vòng lặp chính: đọc command, xử lý homing, giám sát limit và báo done.
  while (Serial.available()) {
    String line = Serial.readStringUntil('\n');
    line.trim();
    if (line.length() > 0) {
      handleCommand(line);
    }
  }

  processHoming();

  if (!homingActive && movementPending && movingIntoLimit()) {
    stopAllMotors();
    xyzValid = false;
    sendError("limit_triggered");
    return;
  }

  if (!homingActive && movementPending && !isBusy()) {
    movementPending = false;
    clearActiveDirs();
    commitPendingIk();
    sendStatus("done");
  }
}

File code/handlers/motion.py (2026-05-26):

"""
handlers/motion.py — Motion Planner chạy trên PC.
Tính toán chuỗi waypoint XYZ (mm); giao tiếp thực tế do SerialHandler đảm nhận.
"""

import math
from config import XY_MAX, Z_HOME, Z_MIN, Z_MAX


# ── Workspace clamp ───────────────────────────────────────────

def clamp_xyz(x: float, y: float, z: float) -> tuple[float, float, float]:
    """Giới hạn tọa độ vào workspace hình trụ."""
    r = math.sqrt(x ** 2 + y ** 2)
    if r > XY_MAX:
        scale = XY_MAX / r
        x, y = x * scale, y * scale
    # Z_MAX âm hơn Z_MIN → dùng max/min đúng chiều
    z = max(Z_MAX, min(Z_MIN, z))
    return round(x, 2), round(y, 2), round(z, 2)


# ── MotionPlanner ─────────────────────────────────────────────

class MotionPlanner:
    """
    Lên lịch các chuỗi chuyển động XYZ:
      - Quỹ đạo tròn liên tục (circle)
      - Pick & Place đơn (build_pp_seq)
      - Pick & Place lặp lại (advanced)
    """

    def __init__(self):
        self.circle_running = False
        self._phase: float = 0.0

        self._pp_seq:  list[tuple[float, float, float, str]] = []
        self._pp_idx:  int = 0
        self._adv_cfg: dict = {}

    # ── Quỹ đạo tròn ─────────────────────────────────────────

    def start_circle(self, angle_deg: float = 0.0):
        self._phase = math.radians(angle_deg)
        self.circle_running = True

    def stop_circle(self):
        self.circle_running = False

    def is_circle_running(self) -> bool:
        return self.circle_running

    def next_circle_point(self, radius: float, z: float,
                           speed_deg: float) -> tuple[float, float, float] | None:
        """
        Trả về điểm XYZ tiếp theo trên vòng tròn tại độ cao z.
        Tự clamp vào workspace.
        """
        if not self.circle_running:
            return None
        x = radius * math.cos(self._phase)
        y = radius * math.sin(self._phase)
        self._phase = (self._phase + math.radians(speed_deg)) % (2 * math.pi)
        return clamp_xyz(x, y, z)

    # ── Pick & Place (simple) ─────────────────────────────────

    def build_pp_seq(self,
                     pick: tuple[float, float, float],
                     place: tuple[float, float, float],
                     travel_z: float):
        """
        Xây chuỗi 8 waypoint Pick & Place:
          ① Nâng an toàn   → (0, 0, travel_z)
          ② Dịch tới GẮP  → (pick_x, pick_y, travel_z)
          ③ Hạ xuống gắp  → (pick_x, pick_y, pick_z)
          ④ Nâng mang vật  → (pick_x, pick_y, travel_z)
          ⑤ Dịch tới THẢ  → (place_x, place_y, travel_z)
          ⑥ Hạ xuống thả  → (place_x, place_y, place_z)
          ⑦ Nâng lên       → (place_x, place_y, travel_z)
          ⑧ Về HOME        → (0, 0, Z_HOME)
        """
        px, py, pz = clamp_xyz(*pick)
        lx, ly, lz = clamp_xyz(*place)
        tz = max(Z_MAX, min(Z_MIN, travel_z))

        self._pp_seq = [
            (0.0, 0.0,  tz,     "① Nâng lên (an toàn)"),
            (px,  py,   tz,     "② Di chuyển tới điểm GẮP"),
            (px,  py,   pz,     "③ Hạ xuống — kẹp/hút vật"),
            (px,  py,   tz,     "④ Nâng lên — mang vật"),
            (lx,  ly,   tz,     "⑤ Di chuyển tới điểm THẢ"),
            (lx,  ly,   lz,     "⑥ Hạ xuống — thả vật"),
            (lx,  ly,   tz,     "⑦ Nâng lên"),
            (0.0, 0.0,  Z_HOME, "⑧ Về HOME"),
        ]
        self._pp_idx = 0

    def next_pp_step(self) -> tuple[float, float, float, str] | None:
        """Trả về waypoint tiếp theo hoặc None nếu chuỗi hết."""
        if self._pp_idx >= len(self._pp_seq):
            return None
        step = self._pp_seq[self._pp_idx]
        self._pp_idx += 1
        return step

    # ── Pick & Place (advanced / repeat) ─────────────────────

    def setup_advanced(self,
                       pick: tuple, place: tuple,
                       travel_z: float, delay: int, repeat: int):
        self._adv_cfg = {
            "pick":     pick,
            "place":    place,
            "travel_z": travel_z,
            "delay":    max(100, delay),
            "repeat":   max(1, repeat),
            "current":  0,
        }

    def adv_cfg(self) -> dict:
        return self._adv_cfg

    def advance(self):
        self._adv_cfg["current"] = self._adv_cfg.get("current", 0) + 1

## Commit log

2026-04-28 Add WIP README and Delta Robot project assets
    [12xball_13.stl, 12xpan_head_tapping_screw_am-28PHT_5x13x12_2-slot-D-S.stl, 12xpan_head_tapping_screw_am-39PHT_4x13x11_6-slot-D-S.stl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]
2026-05-26 Add ESP32 control app and update docs
2026-05-30 Replace repository contents with current project
    [12xball_13.stl, 12xpan_head_tapping_screw_am-28PHT_5x13x12_2-slot-D-S.stl, 12xpan_head_tapping_screw_am-39PHT_4x13x11_6-slot-D-S.stl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]
2026-05-30 thiet ke lai giao dien
    [12xball_13.stl, 12xpan_head_tapping_screw_am-28PHT_5x13x12_2-slot-D-S.stl, 12xpan_head_tapping_screw_am-39PHT_4x13x11_6-slot-D-S.stl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]
2026-05-31 Update delta robot camera calibration and motion
